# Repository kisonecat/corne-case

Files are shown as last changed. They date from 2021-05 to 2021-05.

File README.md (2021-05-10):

# 3D printed case for Corne

Here are models for a 3D printed case for the wonderful [Corne
keyboard](https://github.com/foostan/crkbd) designed by
[@foostan](https://github.com/foostan).  The top piece in this model
covers up the OLED, so this isn't a good choice if you are using
underlighting or the OLED.

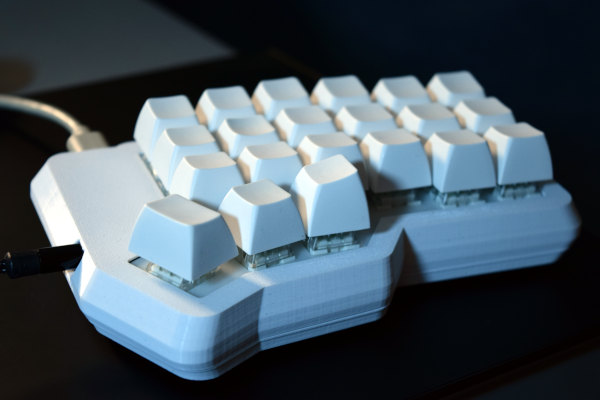
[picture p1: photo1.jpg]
Photo of the right half as viewed from the left hand side


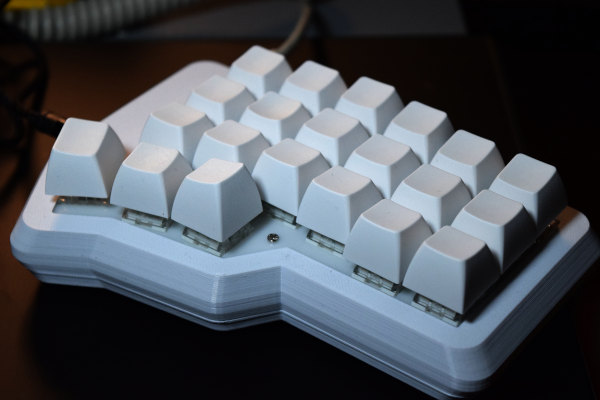
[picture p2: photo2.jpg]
Photo of the right half as viewed from the right hand side


## Structure of project

The top of the case is defined in [top.scad](./top.scad), which I
printed upside down.  The bottom of the case is
[bottom.scad](./bottom.scad).  Both these are built from
[case.scad](./case.scad), which depends on [screw.scad](./screw.scad)
which provides the cutout for a fastener between the two pieces.  One
side of the case has an M3-sized screwhole, and the other has a holder
for a nut.  Melting a small spacer into the plastic would probably be
better.

In this version, the clearance for the TRRS and USB-C cable are both
quite low, so it is a tight fit.  I like the snug fit (since I don't
want the TRRS cable to slip out!) but you may want to make those
cutouts a bit wider.

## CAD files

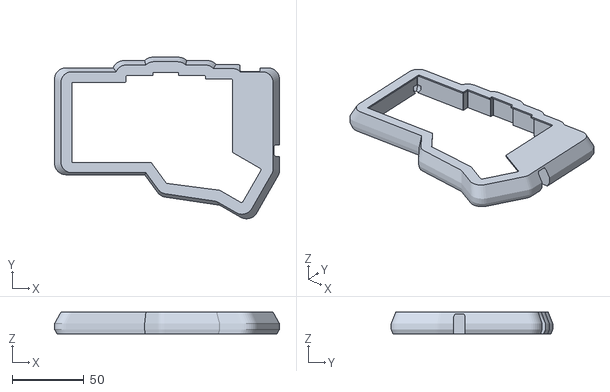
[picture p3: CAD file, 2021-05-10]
top.stl
156.6 x 112.6 x 15.1

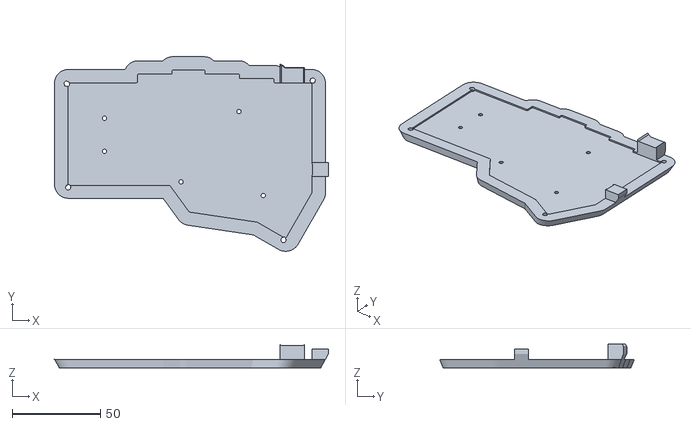
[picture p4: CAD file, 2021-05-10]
bottom.stl
154.9 x 110.1 x 13.5

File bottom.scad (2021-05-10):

include <case.scad>
the_bottom();

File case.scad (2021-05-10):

include <screw.scad>

W = 133.75066;
H = 92.18542;
$fn=32; // for higher resolution circles

// bottom.svg is the PCB plate
module bottom() {
    translate([0,-H,0])
    import("bottom.svg");
}

S = 1.15;
SS = 1.06;
layer_thickness = 0.4;
margin=7;

plate_thickness = 3;
spacer_height = 12;
spacer_diameter = 5;

screw_diameter = 2.5;
screwhead_diameter = 5;
screwhead_height = 3;
keyswitch_bottom = 7;
pcb_thickness = 1.7;
case_thinness = 1.0;

module spacer(x,y) {
    translate([x+4.950/2,-y-4.950/2,0])
    cylinder(h=spacer_height,r=spacer_diameter/2);
}

elitec_offset = 6.972;
elitec_height = 34;
elitec_width = 19;
elitec_thickness = 7.6 - pcb_thickness; 

trrs_offset = 51.7;
trrs_height = 6.2;
trrs_width = 14;
trrs_thickness = 7 - pcb_thickness; 

keyswitch_height = 10;

module keyswitches() {
    translate([0,0,spacer_height])
    translate([W/2,-H/2])
    scale([0.99,0.99,1])
    translate([-W/2,H/2])
    linear_extrude(keyswitch_height) translate([0,-91.39875]) import("top.svg");
    // top.svg is the acrylic plate
}


module elitec() {
       translate([W-elitec_width,-elitec_height-elitec_offset,plate_thickness + spacer_height - keyswitch_bottom]) cube([elitec_width,elitec_height,elitec_thickness]); 
}

module trrs() {
        translate([W-trrs_width,-trrs_height-trrs_offset,plate_thickness + spacer_height - keyswitch_bottom]) cube([trrs_width,trrs_height,trrs_thickness]); 
}

jack_offset = 51.7;
jack_height = 8;
jack_width = 24;
jack_thickness = 8; 
jack_protrusion = 2.5;
inset = 1;

module jack() {
       translate([W-jack_width+20,-jack_height/2 - trrs_height/2 -jack_offset, spacer_height - keyswitch_bottom + pcb_thickness])
   
   hull() {
        translate([0,inset,0])
    cube([jack_width,jack_height-2*inset,jack_thickness]);
       
        translate([0,0,0])
    cube([jack_width,jack_height,jack_thickness-2*inset]);
   }
   
    translate([W,-trrs_height-trrs_offset]) cube([jack_protrusion,trrs_height, spacer_height - keyswitch_bottom + jack_thickness]); 
}


module components() {
        hull() union() { trrs(); elitec(); };
}


usbc_width = 14;
usbc_center = 19 / 2 - 0.5;
usbc_thickness = 5.7; 
inset2 = 0.8;

module usbc() {
         translate([W-usbc_center - usbc_width/2,-elitec_height+27,plate_thickness + spacer_height - keyswitch_bottom + pcb_thickness-1])
    
   hull() {
        translate([inset2,0,0])
    cube([usbc_width-2*inset2,elitec_height,usbc_thickness+1]); 
        
        translate([0,0,inset2])
    cube([usbc_width,elitec_height,usbc_thickness+1-2*inset2]); 
    }
}

// we never render parts(), but it helps to be able to determine the size of the objects that will go into the case
module parts() {
    translate([0,0,spacer_height])
    linear_extrude(plate_thickness) translate([0,-91.39875]) import("top.svg");
    spacer(16.100,23.375);
spacer(16.100,42.125);
spacer(59.350,59.375);
spacer(105.850,67.125);
spacer(92.100,19.625);
    
    translate([0,0,plate_thickness + spacer_height - keyswitch_bottom]) linear_extrude(pcb_thickness) bottom();
}

// the screwholes are truncated cones so they can be removed without needing supports
module screwhole(x,y) {
    // the size of the cutouts on the SVG are 4.95mm, but the input to this module is the corner, so we shift by half 4.95mm in each axis
    translate([x+4.950/2,-y-4.950/2,-case_thinness - screwhead_height])
    union() {
    cylinder(h=10,r=screw_diameter/2);
        
    cylinder(h=screwhead_height,r2=screw_diameter/2,r1=screwhead_diameter/2);
    }
}

// the positions of the corner of the screwholes as measured from the SVG
module screwholes() {
screwhole(16.100,23.375);
screwhole(16.100,42.125);
screwhole(59.350,59.375);
screwhole(105.850,67.125);
screwhole(92.100,19.625);
}

case_top = case_thinness + spacer_height + plate_thickness;

module core() {
minkowski()
{  
bottom();
circle(r=margin);
};
}

module basic() {
translate([0,0,-case_bottom])

intersection() {
translate([W/2,-H/2])
linear_extrude(case_top+case_bottom,scale=S)
translate([-W/2,H/2])
core();

translate([W/2,-H/2,case_top+case_bottom])
scale([1,1,-1])
linear_extrude(case_top+case_bottom,scale=S)
translate([-W/2,H/2])
core();
    
translate([W/2,-H/2,case_top+case_bottom])
scale([SS,SS,-1])
linear_extrude(case_top+case_bottom)
translate([-W/2,H/2])
core();
}
}

module basic2() {
    difference() {
basic();
 
 translate([W/2,-H/2,0])
scale([1.03,1.03,1])
linear_extrude(spacer_height + plate_thickness)
translate([-W/2,H/2])
bottom();
        
        usbc();
        jack();
        keyswitches();
        parts();
        screwholes();
        
        rotate([0,0,180+45])
        translate([6.5,2.5,-case_bottom-0.1])
fastener();
        
    translate([W+2.5,-4.6,-case_bottom-0.1])
rotate([0,0,180-45])
fastener();

  translate([W-14,-H-2.5,-case_bottom-0.1])
rotate([0,0,0])
fastener();

 translate([-2,-65,-case_bottom-0.1])
rotate([0,0,-45])
fastener();
    }
}

  

case_bottom = case_thinness + screwhead_height;


// the height at which to cut the case in half
slice = 4.9;

// the separation between the two pieces includes cutouts for the jacks
module separation() {
      translate([-W,-3*H/2,-case_bottom-1]) 
    cube([3*W,3*H,slice+1]);
    
    translate([W-jack_width+10,-jack_height/2 - trrs_height/2 -jack_offset,-17]) cube([2*jack_width,jack_height,30]); 
    
     translate([W-usbc_center - usbc_width/2,-elitec_height+27,-19]) cube([usbc_width,elitec_height,30]);
}

// this is the bottom of the case
module the_bottom() {
intersection() {
 separation();
 basic2();
}
}

// this is the top of the case
module the_top() {
difference() {
 basic2();
     separation();
}
}

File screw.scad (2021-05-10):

module fastener() {
tol = 1.01;
nut_diameter = 6.3*tol;
nut_height = 3*tol;
screw_diameter = 3.4*tol;
head_diameter = 7.4;
screw_height = 5.0 - nut_height;
head_height = 3;
cut_depth = 3.1;


translate([0,0,screw_height+head_height]) {
/*linear_extrude(nut_height,scale=0)
circle(nut_diameter/2,$fn = 6);*/

    
hull() {
translate([0,0,2*nut_height])
  scale([1,1,-1])
linear_extrude(2*nut_height,scale=0.5)
circle(nut_diameter/2,$fn = 6);
    
translate([0,0,2*nut_height])
  scale([1,1,-1])
linear_extrude(nut_height)
circle(nut_diameter/2,$fn = 6);


translate([-nut_diameter/2,0,nut_height])
cube([nut_diameter,cut_depth,nut_height]);
}
/*
translate([0,cut_depth,2*nut_height])
linear_extrude(5,scale=0.6)
translate([0,-cut_depth,0])
projection()
union() {
    translate([0,0,nut_height])
    linear_extrude(nut_height)
circle(nut_diameter/2,$fn = 6);
translate([-nut_diameter/2,0,nut_height])
cube([nut_diameter,cut_depth,nut_height]);
}
*/

translate([0,0,-screw_height])
cylinder(r1=screw_diameter/2,r2=screw_diameter/2,h=screw_height,$fn=32);


translate([0,0,-screw_height-head_height])
cylinder(r1=head_diameter/2,r2=screw_diameter/2,h=head_height,$fn=32);
}
}

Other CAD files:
top.scad

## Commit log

2021-05-10 initial import
    [bottom.stl, case.scad, screw.scad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]
2021-05-10 better structure for the files
    [bottom.scad, case.scad, top.scad]
